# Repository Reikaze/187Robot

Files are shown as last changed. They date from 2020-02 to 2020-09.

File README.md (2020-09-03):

# Differential Drive Robot
Built a wheeled robot from scratch to do various tasks like Path Following, Line Following, Convoy, Navigate a maze. Had a control System on Pi through Linux & Python, Remote Desktop, Motor Tuning, QTI sensor, Ultrasonic Sensors, built for CSUS EEE 187 Robotics class. Each python file refers to an assignment in the class, as the assignments goes on we added more features to it.

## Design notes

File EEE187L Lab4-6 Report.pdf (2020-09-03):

Lab Report of EEE 187L Labs 4-6.

Geff Freire, Kevin Mai

Abstract - In the Robotics Lab, our goal is to create a robot that is able to specific tasks. Each lab, new sensors or features are added to make the robot capable of doing the objectives that are given.

I. INTRODUCTION
One of the best ways to learn the basics of robotics is to build a robot, and the aim of the EEE 187 Lab class is to learn these through the process of doing the labs.
In each lab the objective was to build up the robot while adding new functions to the robot, and the topic of the lab report is discussing labs 4, 5 and 6 of the EEE 187 class. In the fourth lab, the objective was to have multiple groups to work together to build a convoy robot, one robot that leads the follower robot, follows the leader. In the fifth lab, the objective was to have the robot navigate through the maze. The final and sixth lab was the race - in a tournament bracket with the other robots in the class, the class had a drag race to see which robot was the fastest.
II. COMPONENTS USED TABLE I

COMPONENTS USED IN LAB 4-6

Component | Purpose | Used in Labs
Raspberry Pi 3B+ | Control Systems | All
L298 Motor Driver | Locomotion Control | All
2x 6V DC Motors W/ Encoders | Locomotion | All
Caster Wheel | Stability | All
AA Battery Holder | Power | All
Phone Battery Bank | Power | All
TCRT5000 (QTI) IR Sensor | Detect Line for Following | Lab 4
Ultrasonic Ping Sensors | Sensor for detection | Lab 4 & 5 Lab 4 & 5
LM2596s Voltage Regulator/Buck Converter | Battery Manager | Lab 6
III. | LAB IV
A. Experimental Details
In the fourth lab, the goal of this lab activity was several teams (between 2 and 5) work together to create a convoy of robot. There were two roles in the lab - leader and follower:
Role of the leader - The leader follows a line to reach the destination. It has to stop completely when it reaches the final destination. The role of leader is as follows:
- Follow the line.
- Slow down for a few seconds then accelerate. The change in motion should be noticeable.
- There will be at least one obstacle on the convoy’s path. The leader should be able to detect the obstacle and fully stop. The obstacle will be removed so the convoy can complete the course.
- Stop at the destination point.
Role of the follower - The role of the follower is
- Follow the leader at a constant distance. The distance should be set to any specific value between 20 cm and 40 cm.
- Implement a proportional controller where the speed is proportional to the error between the desired value and the actual value of the distance. This is an important requirement for this lab that will be verified in the code.
- The follower cannot use line detection sensors.

For this lab it was decided to do leader role, and as the leader, the robot needed to have ultrasonic sensors to be added at the front so the robot can stop at the block, and that needed to be integrated with line following code so the robot can go in a path.

Fig 1. Circuit of Robot for Lab I

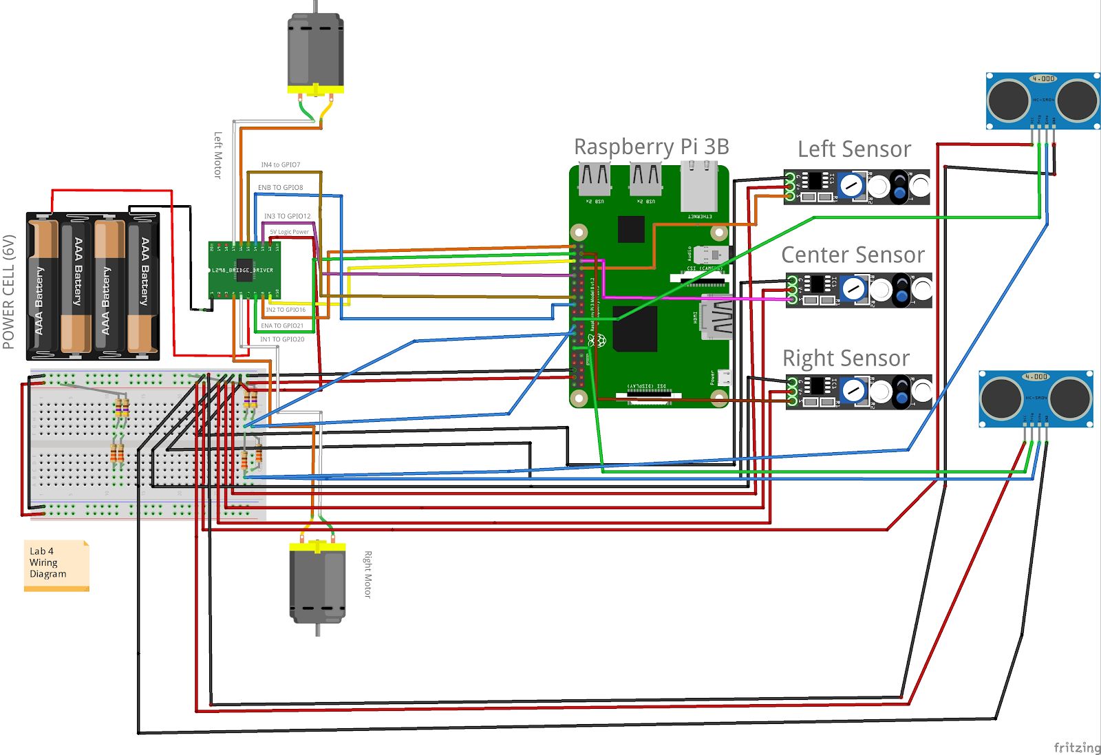
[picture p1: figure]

TABLE II
NEW GPIO PINS ON THE RASPBERRY PI FOR LAB IV
Name in Code | Function | Pin
R_TRIGGER | Trigger Pin of Side Right sensor | 5
R_ECHO | Echo Pin of Side Right | 6
L_ECHO | Echo Pin of Side Left Sensor | 11
L_TRIGGER | Trigger Pin of Side Left Sensor | 9

The robot was wired up according to the Figure I, with the Pi GPIO Pins organized as according to the Table II. The code and calibration work was then done to get the robot working, following the path and then stopping at the point with the block. The cardboard box part in Figure II to the robot rear so the other group’s robot could sense the robot.
B. Results
Fig 2. Robot acting as a leader

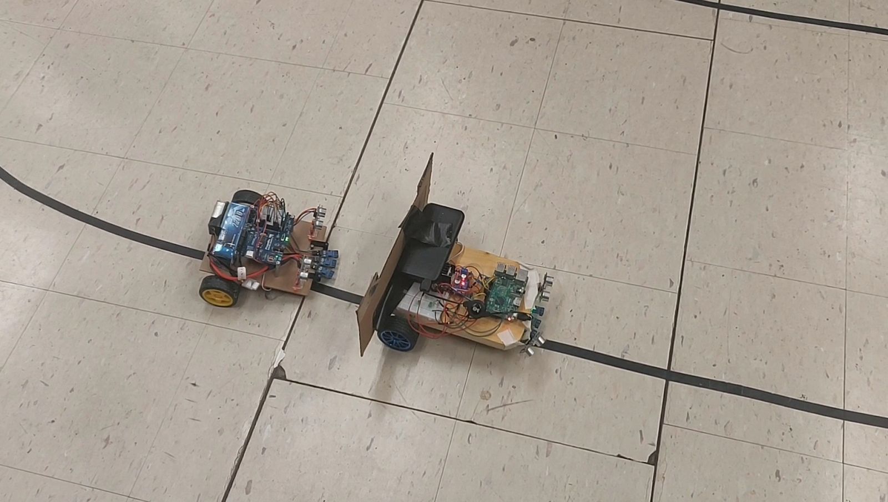
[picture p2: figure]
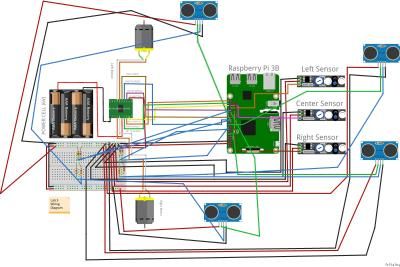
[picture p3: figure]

https://www.dropbox.com/s/h8uj0a42hnhzyl4/VID_20191104_172357_01.mp4?dl=0 (https://www.dropbox.com/s/h8uj0a42hnhzyl4/VID_20191104_172357_01.mp4?dl=0)
During the demo of the lab, the robot successfully followed the path and the follower successfully followed the robot even during a turn. The robot had no issues during operation. The dropbox link above is the video link above, and the lab was demonstrated to the Lab Instructor without problems.
IV. LAB V
A. Experimental Details
In the fifth lab, the objective of this lab was to program the robot to navigate a complex maze. The robot was not allowed to hit any of the walls, and to do that sensors needed to be added but the type of sensors that was used did not matter. There was an optional part of the lab in which the robot would cross a bridge similar to the bridge from Lab II but our group decided not to do this component of the lab. Fig 3. Maze for Lab V

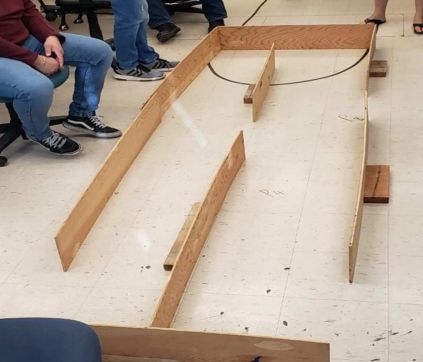
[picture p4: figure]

For this lab, 2 more ultrasonic sensors were added to the robot. From Lab IV, 2 ultrasonic sensors were wired up in the front and in Lab V sensors on the left and right sides were added. The way that the robot handled the maze was that it detected the walls to move and could theoretically do any maze as long as it doesn’t have to go backwards. If 2 of the 3 sensors detected a wall, the robot would turn the other way, if any one of the sensors got too close to the side ones, it would go away from that and if the robot detected walls on the sides it would go straight.
Fig 4. Circuit of Robot for Lab V

TABLE III
NEW GPIO PINS ON THE RASPBERRY PI FOR LAB V
Name in Code | Function | Pin
FR_TRIGGER | Trigger Pin of Front Right PING Sensor | 18
FR_ECHO | Echo Pin of Front Right sensor | 23
FL_ECHO | Echo Pin of Front Left sensor | 24
FL_TRIGGER | Trigger Pin of Front Left sensor | 25
B. Results
Fig 5. Robot Running through the Maze

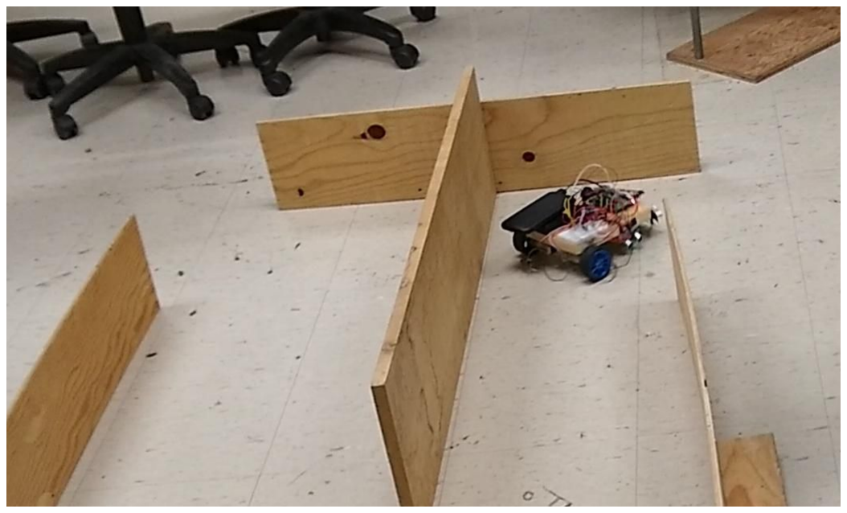
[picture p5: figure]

https://drive.google.com/file/d/19FkPNCYSo-98Qe3u3Lz9Uypw3zpZYG9_/view?usp=sharing (https://drive.google.com/file/d/19FkPNCYSo-98Qe3u3Lz9Uypw3zpZYG9_/view?usp=sharing)
After a few runs with calibration fixes in between each run, the robot was capable of detecting all most of the walls and was able to follow the path, recorded it which is the video link above, and demonstrated to the Lab Instructor without problems.
V. LAB VI
A. Experimental Details
In the 6th lab, the goal of this lab was a EEE187 grand prix race. There are only two requirements for the race:
- The robot should be able to move in a straight line for at least 20 meters.
- The robot should be able to detect an obstacle placed about 20cm in front of it. The race starts when the obstacle is removed. Your robot does not have to stop at the finish line.
All robots that do not complete the race (reach finish line) will be destroyed. The robots have to run in a fairly straight line. The code that was used for the robot during the race was code from Lab 1, just going straight without line following. Calibration work was done to make sure that the robot goes straight.

Fig 6. Picture of Robot Fully Wired Up in Lab VI

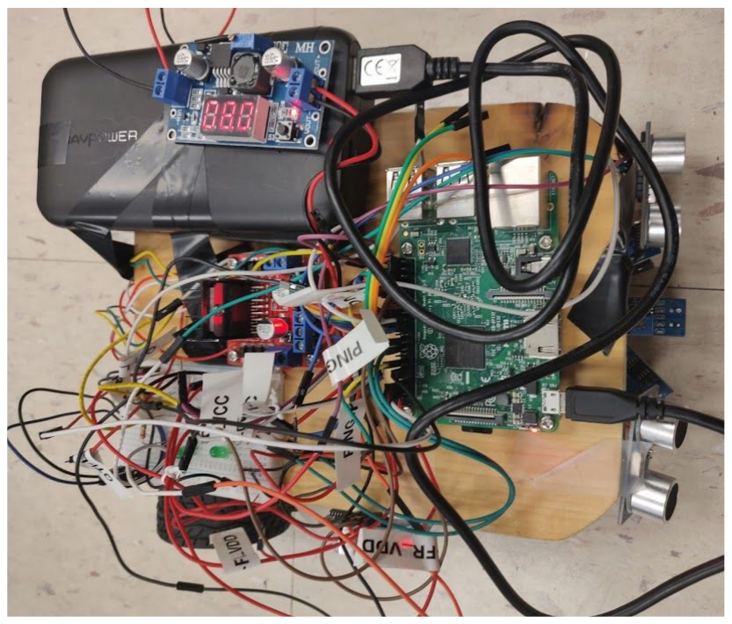
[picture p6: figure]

Fig 7. Circuit of Robot for Lab V

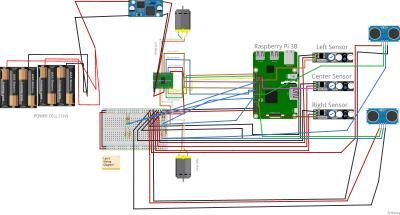
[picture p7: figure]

During Labs IV and V the robot was running into issues because as the batteries drained the power output dropped, so the decision was made to wire according to Figure 7, swapping a 6v battery pack to a 12v power and a LM2596s Voltage Regulator/Buck Converter. As a result, the robot’s runs were more consistent, and ran at peak voltage for longer. To make the robot go faster, the voltage was tweaked to go higher, and during the runs for the race the robot was putting 8v to the robot.
B. Results
Fig 8. Picture of Robot in Race

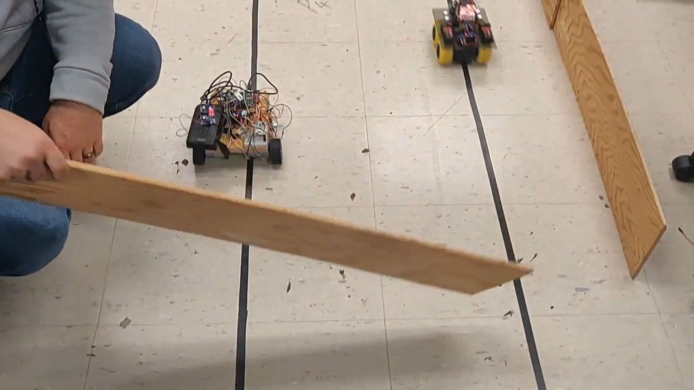
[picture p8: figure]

Fig 9. Results of the Race

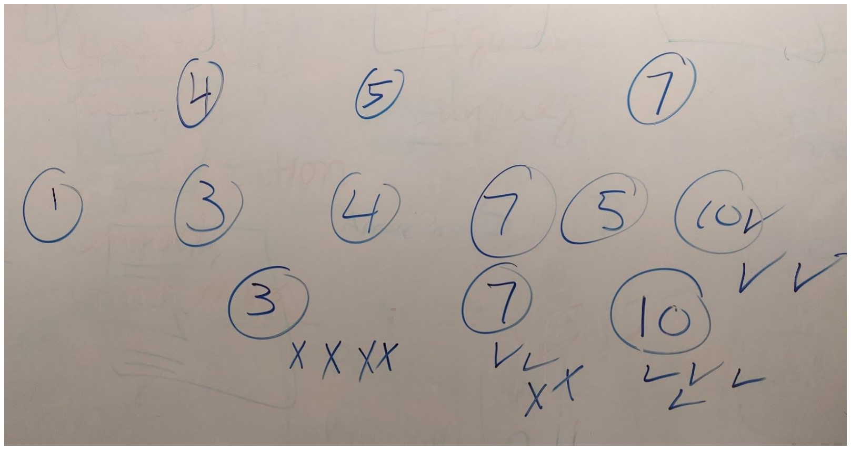
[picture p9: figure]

The robot made it to the 2nd round with Figure 8 showing a part of the lab, beating out a robot before being outperformed by group 10, that ultimately won the tournament. Group 5 was our group, group 10 was the Victors.

VI. CONCLUSION
Throughout these labs we have built a robot that has been a part of a robot convoy, was able to leave a maze, and participated in a race . The completion of these labs were very informative and through implementation more was learned about the concepts of robotics themselves. These labs were mostly smooth sailing, but we had some issues getting Lab 4 done on time. For Lab 5, the challenge was to make sure that our logic was consistent so that the robot would not run into a wall, but this was easily overcome. Lab 6 was smooth sailing with power supply upgrade from 6V to 12 V.. Overall, the lab was a great learning experience and went well.

VII. REFERENCES
[1] Fethi Belkhouche, EEE 187 Lab: Activity 4, Oct 2019
[2] Fethi Belkhouche, EEE 187 Lab: Activity 5, Oct 2019
[3] Fethi Belkhouche, EEE 187 Lab: Activity 6, Nov 2019
[4] “How to use the TCRT5000 IR line follower sensor with the Raspberry Pi” thepihut, Accessed October 10, 2019 [Online]. Available:
https://thepihut.com/blogs/raspberry-pi-tutorials/how-to-use-the-tcrt5000-ir-line-follower-sensor-with-the-raspber ry-pi (https://thepihut.com/blogs/raspberry-pi-tutorials/how-to-use-the-tcrt5000-ir-line-follower-sensor-with-the-raspberry-pi)
[5] “Using a Raspberry Pi Distance Sensor (ultrasonic sensor HR-SR04) “ tutorials-raspberrypi, Accessed on October 21, 2019 [Online]. Available: https://tutorials-raspberrypi.com/raspberry-pi-ultrasonic-sensor-hc-sr04/ (https://tutorials-raspberrypi.com/raspberry-pi-ultrasonic-sensor-hc-sr04/)

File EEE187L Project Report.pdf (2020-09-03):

# Lab Report of EEE 187L Final Project

Kevin Mai, Antony Mylvaganam, Geff Freire

Abstract - This report contains the procedures and findings from the cat bot and mouse bot project. The project has two autonomous robot cars fulfilling the roles of a cat and a mouse. The project aim was to emulate a mouse trying to avoid being captured by a cat.

Keywords - Autonomous robot cars, cat bot, mouse bot

I. INTRODUCTION
This project was inspired from a Sega Dreamcast game called Chu Chu Rocket. The premise of the game was that the player must guide mice through a maze to reach a goal while avoiding cats in the maze. This project emulated the action of the mice and the cat. However, all actions are controlled purely by the autonomous robot cars used as the cat and mouse.

II. COMPONENTS USED TABLE I

COMPONENTS USED IN THE MOUSE ROBOT

Component | Purpose
Raspberry Pi 3B+ | Control Systems
L298 Motor Driver | Locomotion Control
2x 6V DC Motors W/ Encoders | Locomotion
Caster Wheel | Stability
AA Battery Holder (8) | Power
Phone Battery Bank | Power
TCRT5000 (QTI) IR Sensor | Detect Line for Following
Ultrasonic Ping Sensors | Sensor for detection
LM2596s Voltage Regulator/ Buck Converter | Battery Manager

TABLE II
COMPONENTS USED IN THE CAT ROBOT
Components | Purpose
Parallax Activity Board | Control Systems
L298N H-Bridge | DC Motor Control
2x 6V DC Motors | Differential Drive
Caster Wheel | Stability
1x 6V battery | Power to parallax board
1x 14V battery | Power to DC motors
4x Ultrasonic Sensors | Distance Reading
III. | ACRONYMS AND DEFINITIONS

Autonomous Robot - A machine equipped with various sensors which was capable of reacting to the environment it is in from the feedback it receives from its sensors.

QTI - This is an infrared light sender and receiver sensor. This sensor can send a 0 signal or a 1 signal to the control system as feedback. It will send a 0 if the sensor is facing a light absorbing surface, ie black electrical tape. On the other hand, it will send a 1 if the sensor is facing a light reflective surface.

Ultrasonic Sensors - This is a sensor which emits and listens to a high frequency sound to measure distance. This calculation is done by measuring the time taken for the sound to leave the sensor and heard by the sensor. Which is then divided by the speed of sound to find the distance between an object the sound bounced off and the sensor.

Dif erential drive system - This is a drive system which allows a wheeled machine to perform sharp turns in one spot without moving forward or backwards. This maneuverability is capable only because of the two motors which provide movement to the machine. Generally, the two motors are placed opposite of each other and are attached to a wheel.

ICC - Instantaneous Center of Curvature; It is the point at which a car turns.

Activate Range - Both the QTI and Ultrasonic sensors have an activate range. This is the distance a sensor will provide feedback to the control system. The distance on the QTI can be physically changed. This is due to the potentiometer on the QTI sensor, which controls the input voltage for the sensor. On the other hand, the ultrasonic sensor activate range is controlled through the control system. Therefore, the range can be coded to any length between the range of distance the ultrasonic sensor is capable of reading.

IV. PROJECT PROCEDURES

A. Experimental Details
| For this project, our goal was to replicate the
cat and mouse behavior. We originally wanted the cat to work by pathfinding the mouse and the mouse to navigate the maze with ultrasonic sensors but due to time constraints we were not able to implement the systems like that. For the construction of the robots, each robot was built by different groups, and thus the parts and implementation of each bot varies.

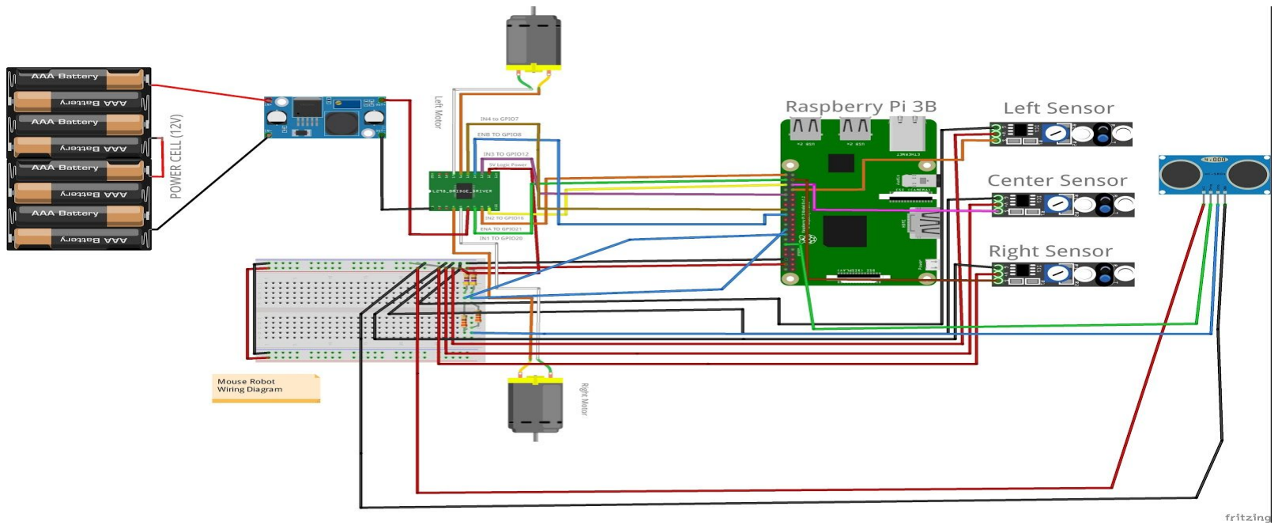
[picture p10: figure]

Figure 1: Mouse Bot Wiring Diagram

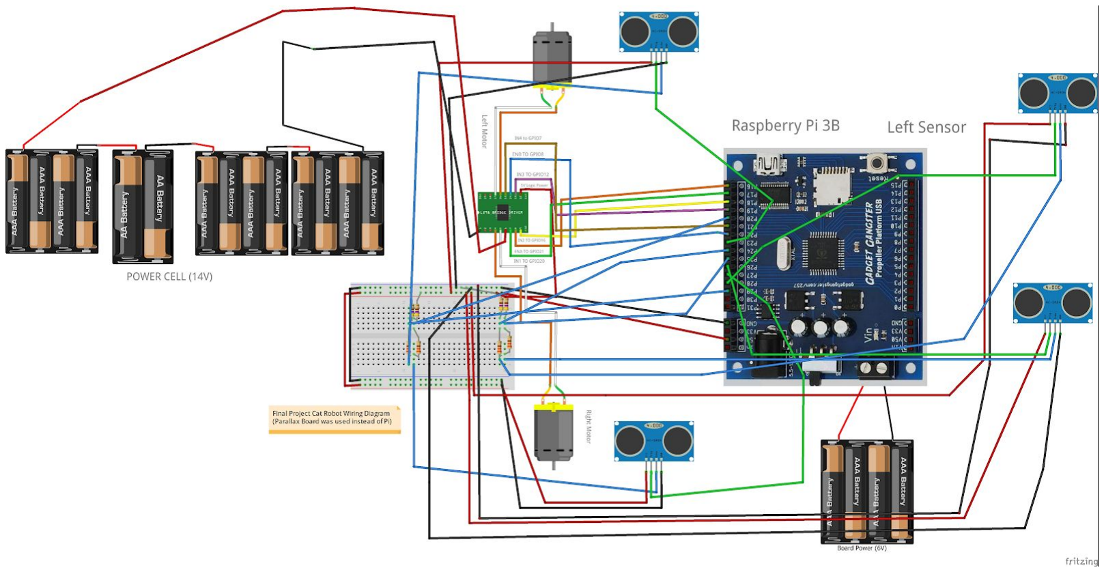
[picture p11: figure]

Figure 2: Cat Bot Wiring Diagram

The control systems are similar in design but different for each of the two robots. While the cat bot used a Parallax WX Activity Board, the mouse bot used a Raspberry Pi 3, as indicated in Table 1 and Table 2 above. There are a few other differences to the robots like the different power supplies but were not done out of necessity but due to implementation. Wiring Diagram for the mouse bot is shown in Figure 1 and the cat bot’s wiring diagram is shown in Figure 2.
Due to the nimbleness needed to emulate cat and mouse behavior, the two robot cars are built on differential drive systems. A differential drive system consists of two motors in parallel powering a car. Table 3 shows how the differential drive works.

The rate of change in direction depends on the speed of the countering action. For example, if the cat bot needs to immediately turn right. The left motor will continue to rotate in a forward direction and the right motor can rotate in the opposite direction or the right motor can stop rotating. These actions will make the cat bot perform an immediate right turn. However, if the right motor was rotating at a slow revolution than the left motor. The cat bot will perform a right turn but at a slower speed as the ICC is farther out from the cat bot. The ICC of the cat bot when it makes an immediate right turn is the center of the right wheel.
TABLE III
THE STATES OF A DIFFERENTIAL DRIVE
States | Explanation
Both motors are rotating in the forward direction | This will move the car forward.
The left motor is rotating in the forward direction but the right motor is rotating in the opposite direction | This will make the car ------perform a right turn.
The right motor is rotating in the forward direction but the left motor is rotating in the opposite direction. | This will make the car perform a left turn.
Both motors are rotating in the backwards rotation. | This will move the car backwards.

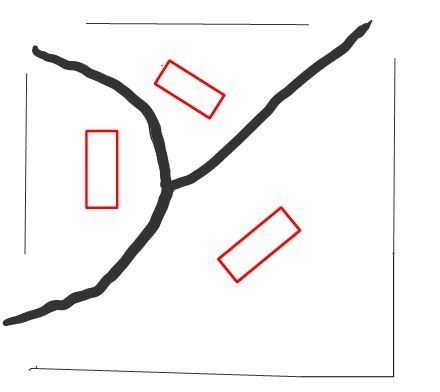
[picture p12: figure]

Figure 3: Maze Design
The maze design used is shown in Figure 3 with the obstacles in red and the thick black lines in the maze being the black tape for the mouse's path. For testing and demonstration, the mouse bot and cat bot are placed in a said maze in Figure 3. The cat bot’s role was to simply hit/catch the mouse bot. The mouse bot’s role was to traverse the maze and find itself out of the maze. In practice, the cat was not aware of where the mouse is, and aims to go to the nearest object in the hopes that the object it hits was the mouse. For the mouse, we implemented navigation through line following - we put black tape throughout the maze and the robot can find its way out using QTI sensors attached to the front of the car.

QTI sensors are short range infrared light emitters and sensors. The sensor will output an IR light and the sensors will receive a digital signal of 0 if it detects a non-reflective surface. Since the maze has a black tape path, which was a non-reflective material, it will provide the necessary feedback to the sensors which will allow the robot to go out. In addition to the QTI sensors, the mouse bot was also equipped with an ultrasonic sensor. The mouse bot will use the ultrasonic sensory data to stop moving if it senses anything in front of it. In this case, if the mouse bot detects the cat bot when it was in front of it, the mouse bot will stop moving until the cat bot was out of the activate range of the ultrasonic sensor which will signal the mouse bot to move again. We also had a mode for the mouse that allows us to control the mouse through the Pi wireless capabilities.
The cat bot also uses ultrasonic sensors. Two sensors in the front and one on each side of the bot. The cat will begin to move in the direction of the nearest object. This means if the cat detected an obstacle in the maze first, it will begin to move towards it. However, if the cat bot detects anything closer, it will change its direction to the nearest object. Since the cat’s goal was to catch the mouse, the cat will have to travel along the maze. However, it was impossible since the cat was incapable of detecting the black tape which was used by the mouse to navigate. Figure 4 shows the mouse robot while Figure 5 shows that cat robot.

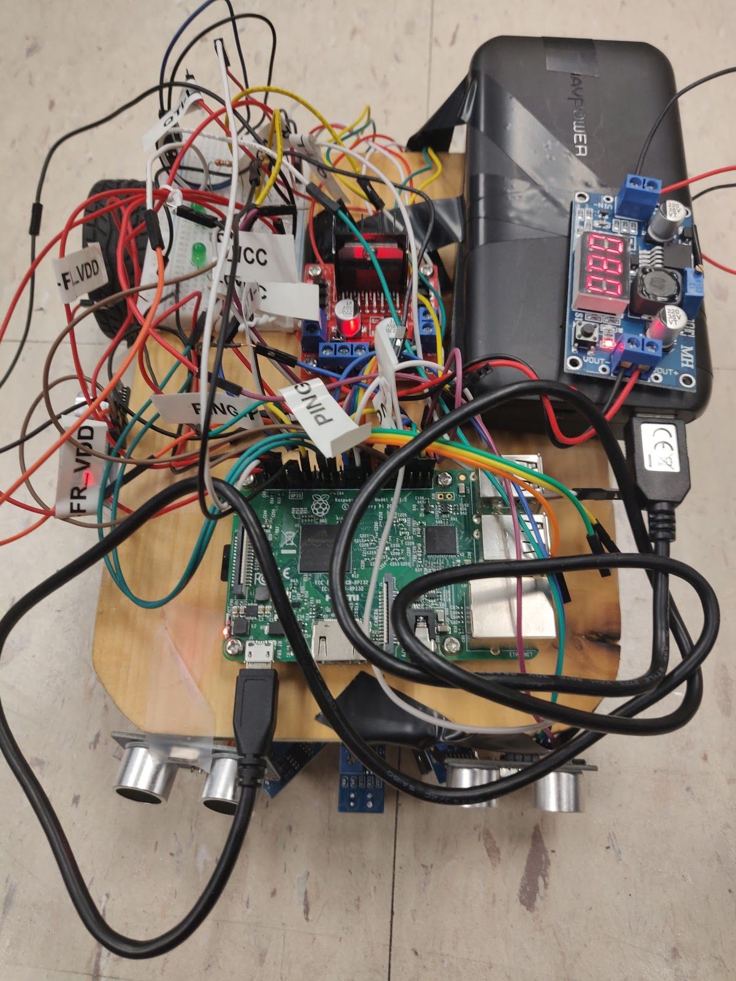
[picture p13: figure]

Figure 4; Mouse Robot

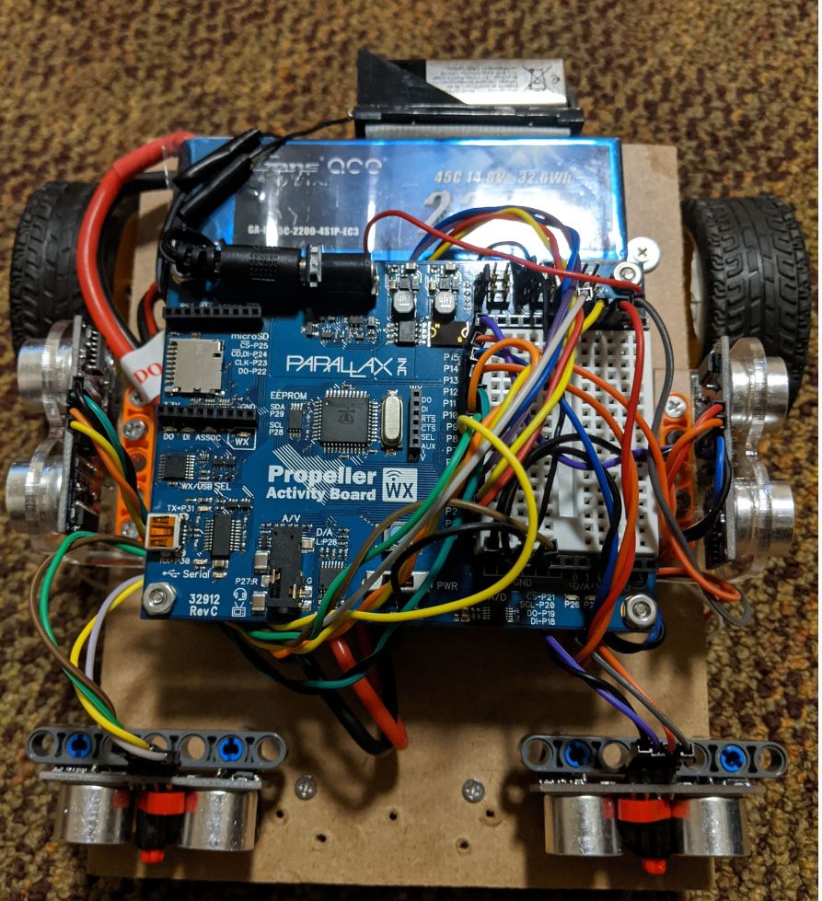
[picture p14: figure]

Figure 5: Cat Robot

V. PROJECT FINDINGS
A. Results
FIRST STRIKE.mp4 (https://drive.google.com/open?id=13ZlYhuH6hE4EmmHcGUefdOCeDhuCu5e_)
user_demo.mp4 (https://drive.google.com/open?id=1eqzevM548HRsWKkTcwmwzligipRQpOxc)
Two demonstrations were done. The first demonstration was to show the cat working successfully and the mouse in its autonomous mode. During the demonstration, the cat runs its algorithm to run to the nearest object and the cat bot successfully caught the mouse bot.
The second demonstration was to show the user control mode and to show the cat not working

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
y. T

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
e. VI. CONCLU

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
n. H

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
s. T

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
y. B

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
e. T

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
e. A

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
w. Demo Video of Mouse Capture https://drive.google.com/drive/folders/17rV9

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
g (https://drive.google.com/drive/folders/17rV9WMjB8mJcbn_jgieVNMQelAcDGj2j?usp=sharing)

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
1: B

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
tp://

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
f (http://athena.ecs.csus.edu/~belkhouf/activity1.pdf)
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
b: A

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
tp://

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
f (http://athena.ecs.csus.edu/~belkhouf/activity3.pdf)
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
b: A

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
tp://

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
f (http://athena.ecs.csus.edu/~belkhouf/activity5.pdf)
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
]. A

v

a

i

l

a

b

l

e: https://thepihut.com/blogs/raspberry-p i

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
i (https://thepihut.com/blogs/raspberry-pi-tutorials/how-to-use-the-tcrt5000-ir-line-follower-sensor-with-the-raspberry-pi)
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
]. A

v

a

i

l

a

b

l

e: https://tutorials-raspberrypi.com/raspberry-pi-ultras o
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
/ (https://tutorials-raspberrypi.com/raspberry-pi-ultrasonic-sensor-hc-sr04/)
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
t. A

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
s://

w

w

w.tu

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
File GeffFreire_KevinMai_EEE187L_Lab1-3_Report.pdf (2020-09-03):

Understanding the Challenges of Locomotion, Lab report of EEE 187L Labs 1-3.

Geff Freire, Kevin Mai

Abstract - In the Robotics Lab, our goal is to create a robot that is able to specific tasks. Each lab we build up the robot while adding new functions to the robot.

I. INTRODUCTION
One of the best ways to learn the basics of robotics is to build a robot yourself, and the aim of the EEE 187 Lab class is to learn these through the process of doing the labs. In each lab we build up the robot while adding new functions to the robot, and for this lab report we are discussing 3 labs. In the first lab, we built the basics of the robot, built with either a differential or akerman drive, controlled using a microcontroller. The second lab the objective was to get the robot to travel a set path which had 4 checkpoints, as well as to have the robot be able to cross a bridge while trying to travel in a straight line. The third lab was line following - we needed to use IR light sensors to follow a black line and get to one of the ends of the paths.

II. COMPONENTS USED TABLE I

COMPONENTS USED IN LAB 1-3

Component | Purpose | Used in Labs
Raspberry Pi 3B+ | Control Systems | All
L298 Motor Driver | Locomotion Control | All
2x 6V DC Motors W/ Encoder | Locomotion | All
Caster Wheel | Stability | All
AA Battery Holder | Power | All
Phone Battery Bank | Power | All

TCRT5000 (QTI)
IR Sensor

Detect Line for
Following

Lab 3

III. LAB I
A. Experimental Details
In the first lab, the goal of this lab activity is to build and calibrate your wheeled mobile robot. During this lab we determined the basics of the robot that would dictate how our robots operate for the rest of our labs.
The lab told us how to model of the robot, built with either a differential or akerman drive, controlled using a microcontroller. We decided to build a differential drive car because controlling it was simpler, and we decided to use a Raspberry Pi 3b as our microcontroller because of how flexible the platform is and because of its wireless capabilities. The lab also wants us to calibrate the robot, and wants us to determine the PWM values:
- when the robot stays stationary.
- that corresponds to clockwise or counterclockwise pure rotational motion.
- that will allow the robot to move forward in a curved path. •that will allow the robot to move in a straight line

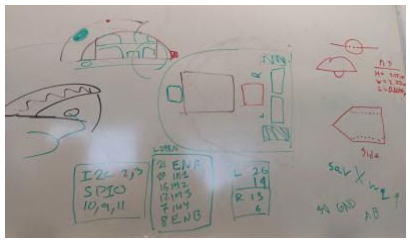
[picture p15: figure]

Fig 1. Drawing of our plans of how we wanted to build the robot
We started by drawing and diagramming how we wanted the robot to be oriented and started by labeling the pin outs.

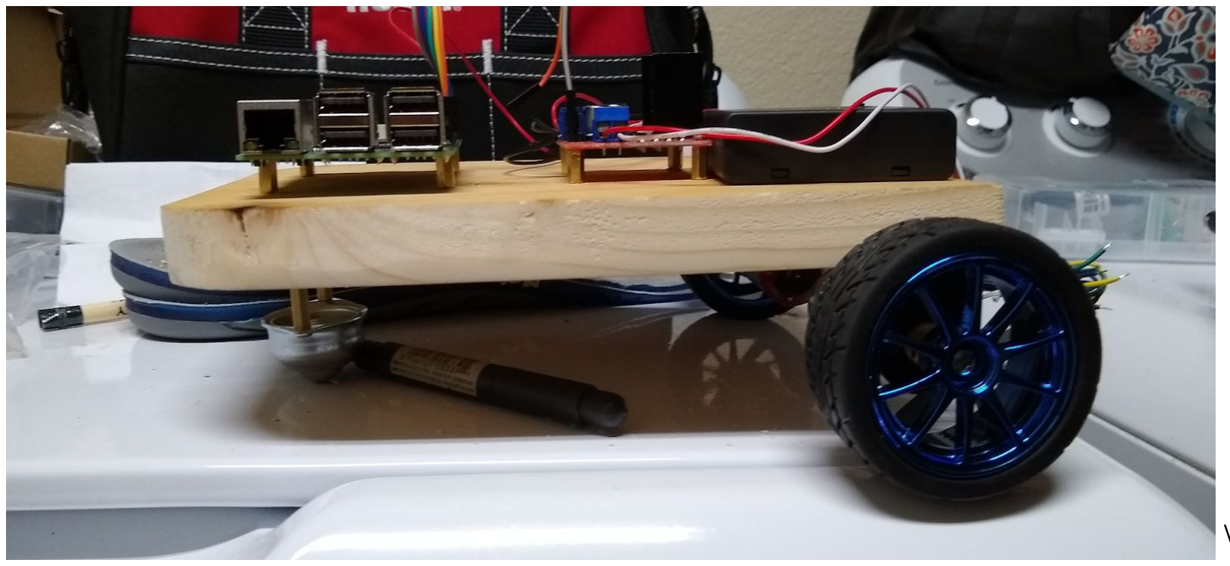
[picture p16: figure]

\
Fig 2. Picture of the robot in construction
Then we cut a piece of wood and started mounting our components onto the platform. In the front, we mounted the Raspberry Pi, in the middle of the robot we mounted the L298N motor controller and at the rear we mounted the battery pack and the tires.

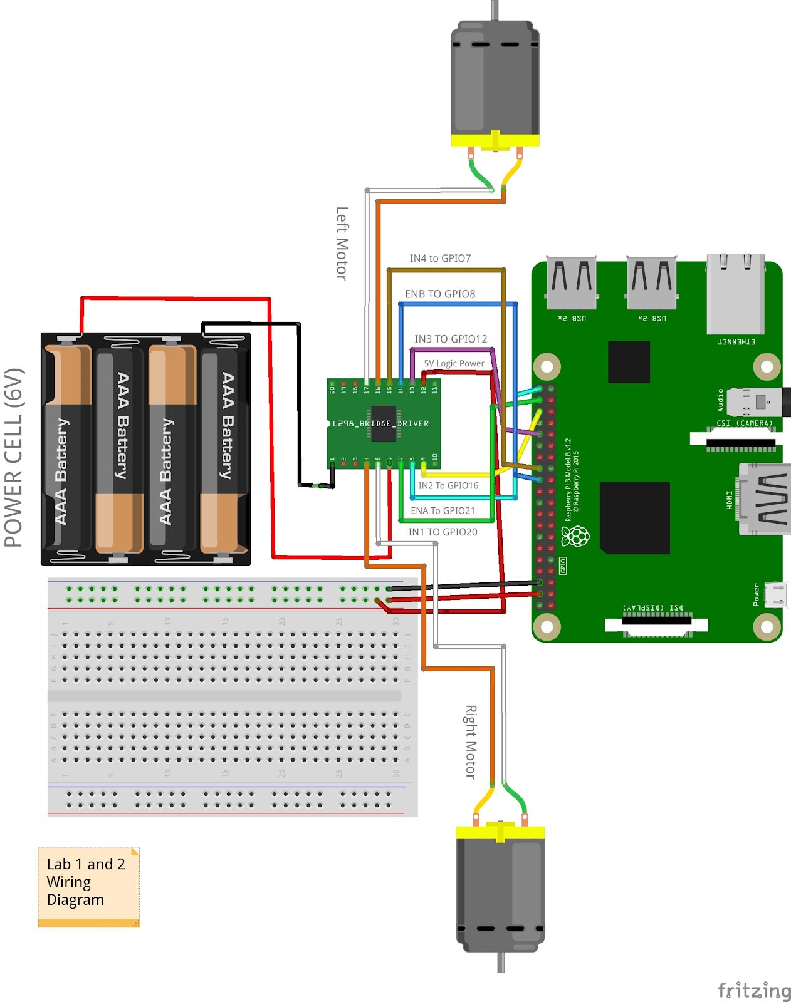
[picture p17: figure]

Fig 3. Wiring Diagram for Lab I & Lab II
TABLE II
GPIO PINS ON THE RASPBERRY PI FOR LAB I
Name in Code | Function | Pin
out1 | Right Wheel + | 20
out2 | Right Wheel - | 16
out3 | Left Wheel - | 12
out4 | Left Wheel + | 7
enA | Enable 1&2 | 21
enB | Enable 3&4 | 8

We then wired up the robot according to the figure 3. The Pi GPIO Pins were organized as according to the table II. We then did the code and calibration work to get the robot working.
B. Results
For the code we wrote a simple program that responded to user input. Going straight used PWM Values 73 for right and 79 for left, and for turning we manipulated the L298N with functions to turn. If both motors were running in the opposite direction, it would turn purely rotationally, if only one turned, it would turn in a curved path, if both were going in the same direction then it would go straight.
After writing the code, we got the robot to move and demoed it to the Lab Instructor without problems.

IV. LAB II
A. Experimental Details
In the second lab, we were tasked to program the robot to perform a desired path. The focus of the program is calibration, tuning the system so it is capable of doing the task on hand. The 2 parts of this lab are 1) Path Planning, navigating from Po to Pf while hitting all specific points in the path and 2) Crossing the bridge, being capable of moving in a straight line so it doesn’t fall off the bridge.

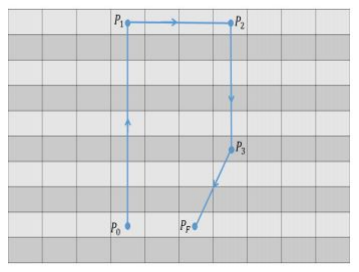
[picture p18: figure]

Fig 4. Path Required for Lab II Part I

We didn’t need to change any of the hardware so the work required is mostly calibration. The hardest part of calibration was going straight for the path - the floor is not even so even if we tuned the robot to go straight it wouldn’t necessarily go the same way every time. Once we got the robot to go straight, we had to calibrate the robot to get the robot to turn at the given time for the various angles, and then after a few shots we got it working

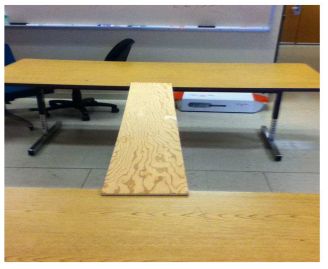
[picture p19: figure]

Fig 5. Bridge needed to cross for Part II
For Part 2, we already had going in a straight line working well so it was a matter of just running it. Part 2 went smoothly without any major modifications.
B. Results
https://drive.google.com/open?id=1m5DfGpX31mJVIc7fmKb Qc3Oo6bdDI1Ag (https://drive.google.com/open?id=1m5DfGpX31mJVIc7fmKbQc3Oo6bdDI1Ag)
After calibrating the robot we got it to follow the path, recorded it which is the video link above, and demonstrated part 1 to the Lab Instructor without problems. Part 2 we demoed it going on the bridge straight in class.
V. LAB III
A. Experimental Details

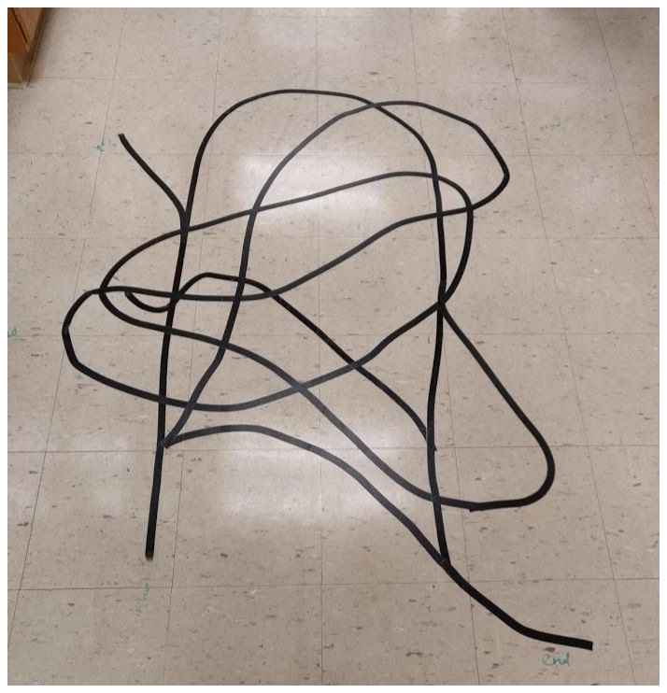
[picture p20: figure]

Fig 6. Obstacle path for Lab 3 that robot needed to get the end of
In the third lab, the goal is to get our robot to follow a line to reach a final destination point at the end of the line. The lab had black tape on the floor with endpoints, the robot had to be capable of following while not getting completely lost in the maze of lines. We had to determine what sensor we wanted to use and we decided on a QTI infrared sensor - The light emitted by the LED bounces off a surface of an object, and is detected by the phototransistor.

Fig 7. Wiring Figure for Lab III
We started the lab by trying to mount the QTI sensors at the very bottom of the robot but we ran into issues while doing it. We moved the QTI sensors to the front but originally only put 2 sensors on the robot which lead to issues so we had to change it to 3. Once we wired them up as according to Figure 7 above and tweaked our code, we had it line following successfully.

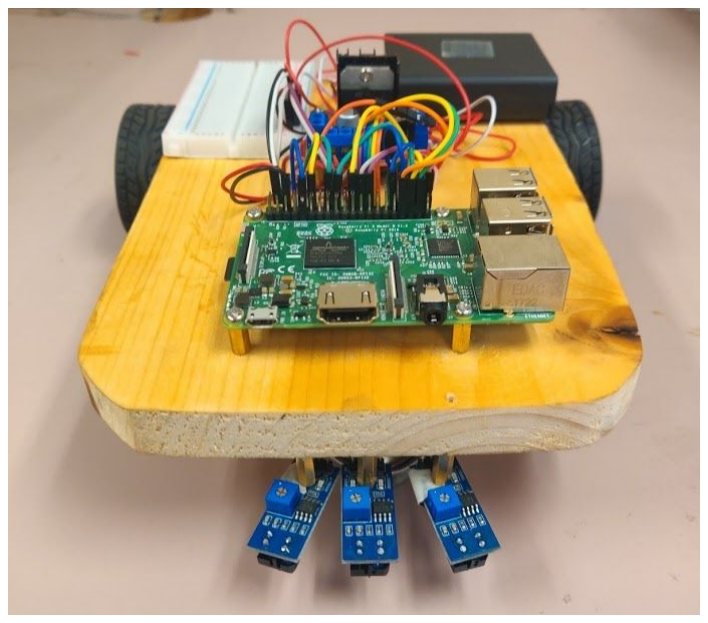
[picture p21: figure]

Fig 8b. Robot for Lab III

B. Results
https://drive.google.com/open?id=19ipKMwBzhhzg7cB6Y6geSi79l5E_KHZN (https://drive.google.com/open?id=19ipKMwBzhhzg7cB6Y6geSi79l5E_KHZN)
After calibrating the robot we got it to follow a path and get to an end point, recorded it which is the video link above, and demonstrated it to the Lab Instructor.

VI. CONCLUSION
Throughout these labs we have built a robot that successfully is able to move around, follow a path, and line follow. These labs have taught us how these components work and have taught us how we would implement the component into real devices. These labs were mostly smooth sailing, and we never got stuck at any point in time. For the first lab we were able to do it just in the lab time, while the 2nd and 3rd labs needed a session outside of class for us to finish. There isn’t anything we’d change with the labs, the lab was a great learning experience and went well.
VII. REFERENCES
[1] Fethi Belkhouche, EEE 187 Laboratory Activity 1: Building the robot, Aug 2019
[2] Fethi Belkhouche, EEE 187 Lab: Activity 2, Sept 2019
[3] Fethi Belkhouche, EEE 187 Lab: Activity 3, Sept 2019

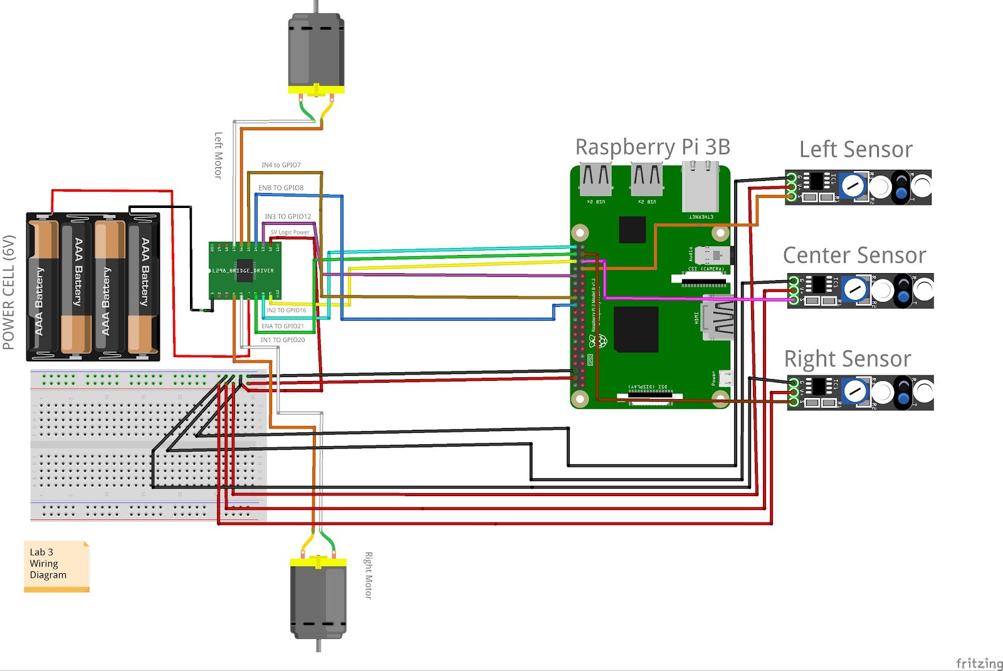
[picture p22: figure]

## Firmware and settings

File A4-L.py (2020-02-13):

#******************************************
#*Programmers: Geff Freire and Kevin Mai *
#*Program 4: A4.py                        *
#*Lab 3                                   *
#*Class: EEE 187L (Group Johnny 5)        *
#*Date: October 22, 2019                  *
#******************************************
#forward function
def forward():
  print('go FWD')
  GPIO.output(out1,GPIO.HIGH)
  GPIO.output(out2,GPIO.LOW)
  GPIO.output(out3,GPIO.LOW)
  GPIO.output(out4,GPIO.HIGH)
  print("forward")

#backward function
def backward():
  print("go REV")
  GPIO.output(out1,GPIO.LOW)
  GPIO.output(out2,GPIO.HIGH)
  GPIO.output(out3,GPIO.HIGH)
  GPIO.output(out4,GPIO.LOW)
  print("backwards")

#stop function
def stop():
  print("stop")
  GPIO.output(out1,GPIO.LOW)
  GPIO.output(out2,GPIO.LOW)
  GPIO.output(out3,GPIO.LOW)
  GPIO.output(out4,GPIO.LOW)
#Turn Left  
def left():
  print("go left")
  GPIO.output(out1,GPIO.HIGH)
  GPIO.output(out2,GPIO.LOW)
  GPIO.output(out3,GPIO.LOW)
  GPIO.output(out4,GPIO.LOW)
  print("left")
#Turn Right
def right():
  print("go right")
  GPIO.output(out1,GPIO.LOW)
  GPIO.output(out2,GPIO.LOW)
  GPIO.output(out3,GPIO.LOW)
  GPIO.output(out4,GPIO.HIGH)
  print("right")

def straight():
  p.start(73)#right (Magic: 74 (p) and 79 (q)))
  q.start(79)

def forwardLeft():
  print("forward left")
  p.start(73)#right (Magic: 74 (p) and 79 (q)))
  q.start(82)

def forwardRight():
  print("forward right")
  p.start(76)
  q.start(79)

#UltraSonic Functions
def ReadL():
	#print ("Reading Left")
	# set Trigger to HIGH
	GPIO.output(L_TRIGGER, True)
 
    # set Trigger after 0.01ms to LOW
	time.sleep(0.00001)
	GPIO.output(L_TRIGGER, False)
 
	StartTime = time.time()
	StopTime = time.time()
 
    # save StartTime
	while GPIO.input(L_ECHO) == 0:
		StartTime = time.time()
 
    # save time of arrival
	while GPIO.input(L_ECHO) == 1:
		StopTime = time.time()
	#print ("Left Math Time!")
    # time difference between start and arrival
	TimeElapsed = StopTime - StartTime
    # multiply with the sonic speed (34300 cm/s)
    # and divide by 2, because there and back
	L_distance = (TimeElapsed * 34300) / 2
    
	return L_distance
	

def ReadR():
	# set Trigger to HIGH
	GPIO.output(R_TRIGGER, True)
	#print("Reading Right")
    # set Trigger after 0.01ms to LOW
	time.sleep(0.00001)
	GPIO.output(R_TRIGGER, False)
 
	StartTime = time.time()
	StopTime = time.time()
	 
    # save StartTime
	while GPIO.input(R_ECHO) == 0:
		StartTime = time.time()
    # save time of arrival
	while GPIO.input(R_ECHO) == 1:
		StopTime = time.time()
	#print("Right Math Time!")
    # time difference between start and arrival
	TimeElapsed = StopTime - StartTime
    # multiply with the sonic speed (34300 cm/s)
    # and divide by 2, because there and back
	R_distance = (TimeElapsed * 34300) / 2
	
	return R_distance 
	
#Randomly stop:
def generator():
	return randint(1,10)

#import
import RPi.GPIO as GPIO          
from time import sleep
import time
from random import randint
#Pin Modes for I2C (for later)
#I2CLK = 2
#I2DAT = 3

#L298 Bridge pin definitions
#Outs are the Ins of the Bridge. 
out1 =20 #right wheel +
out2 = 16 #right wheel -
out3 = 12 #left wheel -
out4 = 7 #left wheel +
enA = 21 #enable 1 & 2
enB = 8  #enable 3 & 4

#QTI Pin Sensor Definitions 
left_sensor = 13 #left QTI
center_sensor = 19 #Center QTI
right_sensor = 26 #right QTI

#UltraSonics Definitions (4)
R_TRIGGER=18
R_ECHO=23
L_ECHO=24
L_TRIGGER=25

#GPIO Setup
GPIO.setwarnings(False)
GPIO.setmode(GPIO.BCM)

#LN298D Bridge Control Pins
GPIO.setup(out1,GPIO.OUT)
GPIO.setup(out2,GPIO.OUT)
GPIO.setup(enA,GPIO.OUT)
GPIO.setup(out3,GPIO.OUT)
GPIO.setup(out4,GPIO.OUT)
GPIO.setup(enB,GPIO.OUT)

#Motor Output Pins 
GPIO.output(out1,GPIO.LOW)
GPIO.output(out2,GPIO.LOW)
GPIO.output(out3,GPIO.LOW)
GPIO.output(out4,GPIO.LOW)

#Light Sensor Pins 
GPIO.setup(left_sensor, GPIO.IN)
GPIO.setup(center_sensor, GPIO.IN)
GPIO.setup(right_sensor, GPIO.IN)

#UltraSonic Pin Setups
GPIO.setup(L_TRIGGER, GPIO.OUT)
GPIO.setup(R_TRIGGER, GPIO.OUT)
GPIO.setup(L_ECHO, GPIO.IN)
GPIO.setup(R_ECHO, GPIO.IN)

#PWM Controllers
p=GPIO.PWM(enA,500) #original 500 for both A and B
q=GPIO.PWM(enB,500)



#start function
p.start(70)#right (Magic: 74 (p) and 79 (q))) QTI Magic: q= 55 and p = 60
q.start(73)#left 
print("hi\n")



#print("The default speed & direction of motor is LOW & Forward.....")
#print("g-go s-stop b-backward f-forward L_left R_right e-exit")
#print("\n")
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
